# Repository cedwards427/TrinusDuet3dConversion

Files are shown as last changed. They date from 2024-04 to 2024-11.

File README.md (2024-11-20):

# TrinusDuet3dConversion
Configuration and models created to convert a Kodama Trinus (Panowin F1) 3D printer to Duet 3 Mini 5+ control board and an E3D Hemera hot end.

The Kodama Trinus is (was?) a small, rigid framed, 3d printer based around modular, worm-gear driven axis assemblies. It initially ran with a proprietary controller board with a proprietary slicer (slicing to 'p-code'). The Trinus was (as far as I can tell) developed and manufactured by Panowin (as the F1, with the Pango slicer) and was marketed and imported to the US by Kodama. Kodama offered several upgrades including an optional enclosure, laser engraver, and upgraded heated bed. Years later, Kodama released the "Bardo" board with Marlin firmware.

I purchased a Kodama Trinus through their Kickstarter campaign and successfully printed in PLA for a while. When I attempted to print more interesting materials (TPU and PETG) the Trinus extruder could not keep up. I attempted to upgrade to an E3D Hemera. Around this time, I found another mostly complete Trinus for sale (sans extruder) and bought it (and another Hemera!). I never got the Hemera working properly with the Trinus -- I could not update the Marlin firmware on the Bardo board without reverse engineering it.

Several years later, I finally got tired of having two 3D printers sitting collecting dust, so I purchased 2 Duet3D Duet 3 Mini 5+ (Ethernet) boards. With some internet sleuthing I was able to figure out all of the configuration settings for the Trinus and the Hemera. I also designed some simple brackets to hold the Duet board to the Trinus frame. I have one printer completely up and running and am about to convert the second one.

Update: Both printers are up and running. I made some additional updates to the heated bed plates and have been working out a bed-leveling process. In the meantime, I have purchased some additional Bambu Lab printers but will continue to tinker with the Kodama Trinus machines.

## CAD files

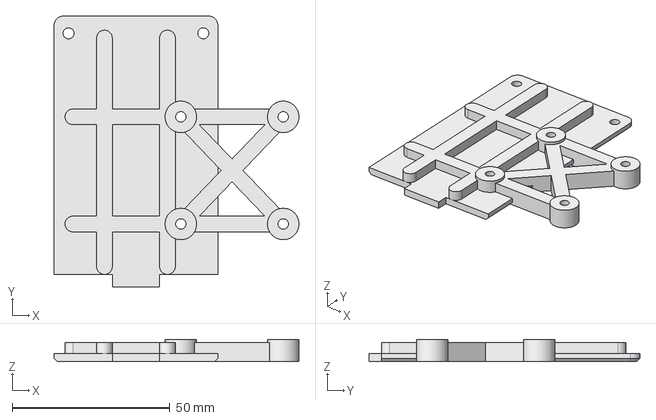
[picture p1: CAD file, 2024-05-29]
3dmodels/TrinusHemeraBracket.FCStd
77.8 x 86.0 x 7.00 mm

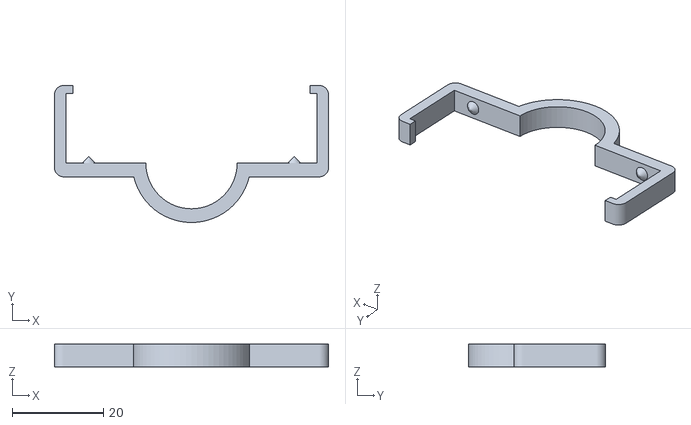
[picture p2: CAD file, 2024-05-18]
3dmodels/Trinus_Wire_Clip-Body.stl
60.0 x 30.0 x 5.00

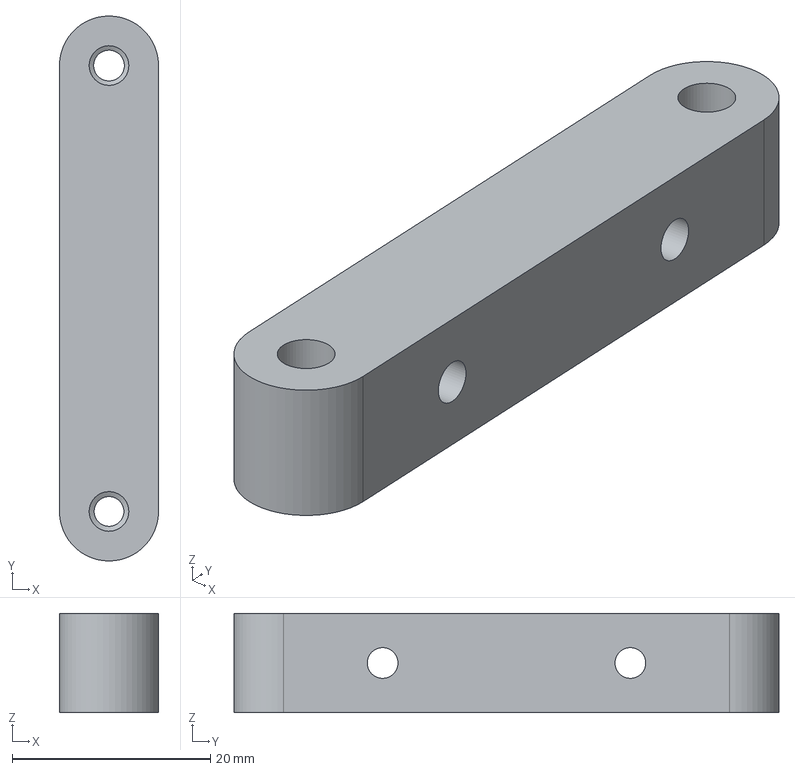
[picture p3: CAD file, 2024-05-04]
3dmodels/Trinus_Bracket.FCStd
10.0 x 55.0 x 10.0 mm

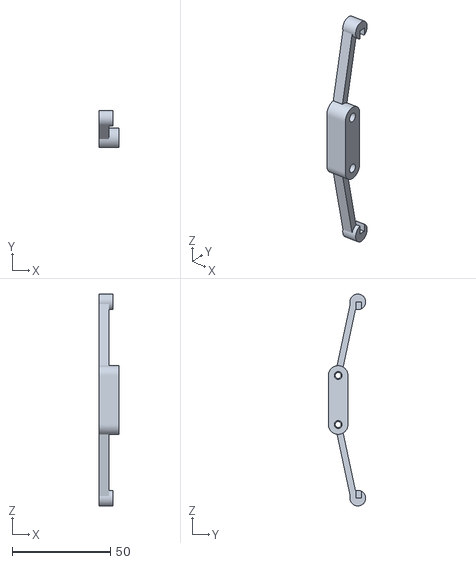
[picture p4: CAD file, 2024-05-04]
3dmodels/Duet3d_Bracket-Body.stl
10.0 x 19.0 x 108.0

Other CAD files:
3dmodels/TrinusHemeraBracket-Body.stl
3dmodels/Trinus_Wire_Clip.FCStd
3dmodels/Duet3d_Bracket.FCStd
3dmodels/Trinus_Bracket-Body.stl

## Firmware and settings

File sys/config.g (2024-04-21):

; Configuration file for RepRapFirmware on Duet 3 Mini 5+ Ethernet
; executed by the firmware on start-up
;
; generated by RepRapFirmware Configuration Tool v3.5.0-rc.4+1 on Sat Apr 13 2024 08:25:59 GMT-0400 (Eastern Daylight Time)

; General
G90 ; absolute coordinates
M83 ; relative extruder moves
M550 P"trinusb" ; set hostname

; Network
M552 P0.0.0.0 S1 ; configure Ethernet adapter
M586 P0 S1 ; configure HTTP

; Smart Drivers
M569 P0.0 S1 D2 ; driver 0.0 goes forwards (X axis)
M569 P0.1 S1 D2 ; driver 0.1 goes forwards (Y axis)
M569 P0.2 S1 D2 ; driver 0.2 goes forwards (Z axis)
M569 P0.3 S1 D2 ; driver 0.3 goes forwards (Z axis)
M569 P0.4 S1 D2 ; driver 0.4 goes forwards (extruder 0)

; Motor Idle Current Reduction
M906 I30 ; set motor current idle factor
M84 S30 ; set motor current idle timeout

; Axes
M584 X0.0 Y0.1 Z0.2:0.3 ; set axis mapping
M350 X16 Y16 Z16 I1 ; configure microstepping with interpolation
M906 X1000 Y1000 Z1000 ; set axis driver currents
M92 X227.5 Y227.5 Z227.5 ; configure steps per mm
M208 X0:120 Y0:120 Z0:120 ; set minimum and maximum axis limits
M566 X900 Y900 Z12 ; set maximum instantaneous speed changes (mm/min)
M203 X6000 Y6000 Z180 ; set maximum speeds (mm/min)
M201 X3000 Y3000 Z100 ; set accelerations (mm/s^2)

; Extruders
M584 E0.4 ; set extruder mapping
M350 E16 I1 ; configure microstepping with interpolation
M906 E1000 ; set extruder driver currents
M92 E409 ; configure steps per mm
M566 E120 ; set maximum instantaneous speed changes (mm/min)
M203 E3600 ; set maximum speeds (mm/min)
M201 E250 ; set accelerations (mm/s^2)

; Kinematics
M669 K0 ; configure Cartesian kinematics

; Probes
M558 K0 P0 H5 F120 T6000 ; configure manual probe via slot #0
G31 P500 X0 Y0 Z0.7 ; set Z probe trigger value, offset and trigger height

; Endstops
M574 X1 P"!io0.in" S1 ; configure X axis endstop
M574 Y1 P"!io1.in" S1 ; configure Y axis endstop
M574 Z1 P"!io2.in" S1 ; configure Z axis endstop

; Sensors
M308 S0 P"temp0" Y"thermistor" A"Heated Bed" T100000 B4725 C7.06e-8 ; configure sensor #0
M308 S1 P"temp1" Y"thermistor" A"Nozzle" T100000 B4390 C7.06e-8 ; configure sensor #1

; Heaters
; Nozzle
M950 H0 C"out0" T1 ; create heater #1
M143 H0 P0 T1 C0 S300 A0 ; configure heater monitor #0 for heater #1
M307 H0 R2.282 K0.345:0.000 D4.87 E1.35 S1.00 B0 V12.3 ; configure model of heater #1
; Heated Bed
M950 H1 C"out1" T0 ; create heater #0
M143 H1 P0 T0 C0 S140 A0 ; configure heater monitor #0 for heater #0
M307 H1 R0.540 K0.691:0.000 D3.57 E1.35 S1.00 B0 ; configure model of heater #0

; Heated beds
M140 P0 H1 ; configure heated bed #0

; Fans
M950 F0 C"out5" ; create fan #0
M106 P0 S127 L0 X1 B0.1 ; configure fan #0
M950 F1 C"out4" ; create fan #1
M106 P1 S0 B0.1 H1 T45 ; configure fan #1

; Tools
M563 P0 D0 H0 F0 ; create tool #0
M568 P0 R0 S0 ; set initial tool #0 active and standby temperatures to 0C

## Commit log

2024-04-21 Added 3d model for controller board bracket
    [TrinusDuetHolder-Body.stl, TrinusDuetHolder.FCStd]
2024-04-21 Uploaded 'sys' files for Trinus/Hemera
    [bed.g, config.g, homeall.g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]
2024-05-04 Updated 2-piece brackets
    Updated 2-piece brackets to hold the Duet3D controller board to the back of the Trinus. The brackets are easier to print without supports but require twice as many threaded inserts and additional 20 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
    [Duet3d_Bracket-Body.stl, Duet3d_Bracket.FCStd, Trinus_Bracket-Body.stl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]
2024-05-18 Version 1.0 of clip-on wire holders for rail
    [Trinus_Wire_Clip-Body.stl, Trinus_Wire_Clip.FCStd]
2024-05-18 Version 1.1 of wire management clips
    [Trinus_Wire_Clip-Body.stl, Trinus_Wire_Clip.FCStd]
2024-05-29 Initial version of Hemera bracket for Trinus
    The first functional version of the Hemera bracket for the Trinus. PETG is a little springy and the mounting holes for the Hemera are a little tricky so this may require a redesign after testing.
    [TrinusHemeraBracket-Body.stl, TrinusHemeraBracket.FCStd]
